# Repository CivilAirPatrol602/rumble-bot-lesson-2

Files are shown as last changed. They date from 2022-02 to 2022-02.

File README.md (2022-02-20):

# Rumble-Bot Lesson 2

Lesson 2 focuses on soldering the Rumble-Bot microcontroller board and designing
the Rumble-Bot input/output board by placing components and copper traces.

## Directory Contents

* [01-power](01-power/README.md): The completed Ardustack power board; cadets
  assemble and solder a power board as part of Lesson 1
* [02-processor](02-processor/README.md): The completed Ardustack
  microcontroller board; cadets assemble and solder a microcontroller board as
  part of Lesson 2
* [03-input-output](03-input-output/README.md): The Ardustack input/output
  board; cadets place components and route the board traces as part of Lesson 2
* [LICENSE](LICENSE): License for the non-hardware portions of the repository
* [README.md](README.md): This document

## License

Written by Bradley Denby  
Other contributors: None

See the [LICENSE](LICENSE) file for license details.

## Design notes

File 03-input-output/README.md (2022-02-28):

# Ardustack Input/Output Board

The I/O PCB for Ardustack, a through-hole Arduino stack

## Directory Contents

* **3d-models**: Contains component `.stp` files for import
* **components**: Contains component `.lib` files for import
* **datasheets**: Contains component datasheets
* **documentation**: Contains `.pdf` documentation files
* **footprints**: Contains component `.kicad_mod` files for import
* **gerbers**: Contains the most recent set of Gerber files
* **kicad**: Contains the KiCad project files
* **versions**: Contains `.zip` files of Gerber files submitted for manufacture
* [BOM.csv](BOM.csv): Bill of materials
* [LICENSE](LICENSE): License for the Ardustack power management PCB hardware
* [NOTES.md](NOTES.md): Useful notes if setting up a KiCad project from scratch
* [README.md](README.md): This document

## License

Written by Bradley Denby  
Other contributors: None

The Ardustack power management PCB is licensed as described in the
[LICENSE](LICENSE) file contained in this directory. All other materials, such
as documentation, are licensed as described in the top-level
[LICENSE](../LICENSE) file or under other applicable licenses.

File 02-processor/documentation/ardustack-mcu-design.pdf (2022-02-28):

## Ardustack MCU Board Design

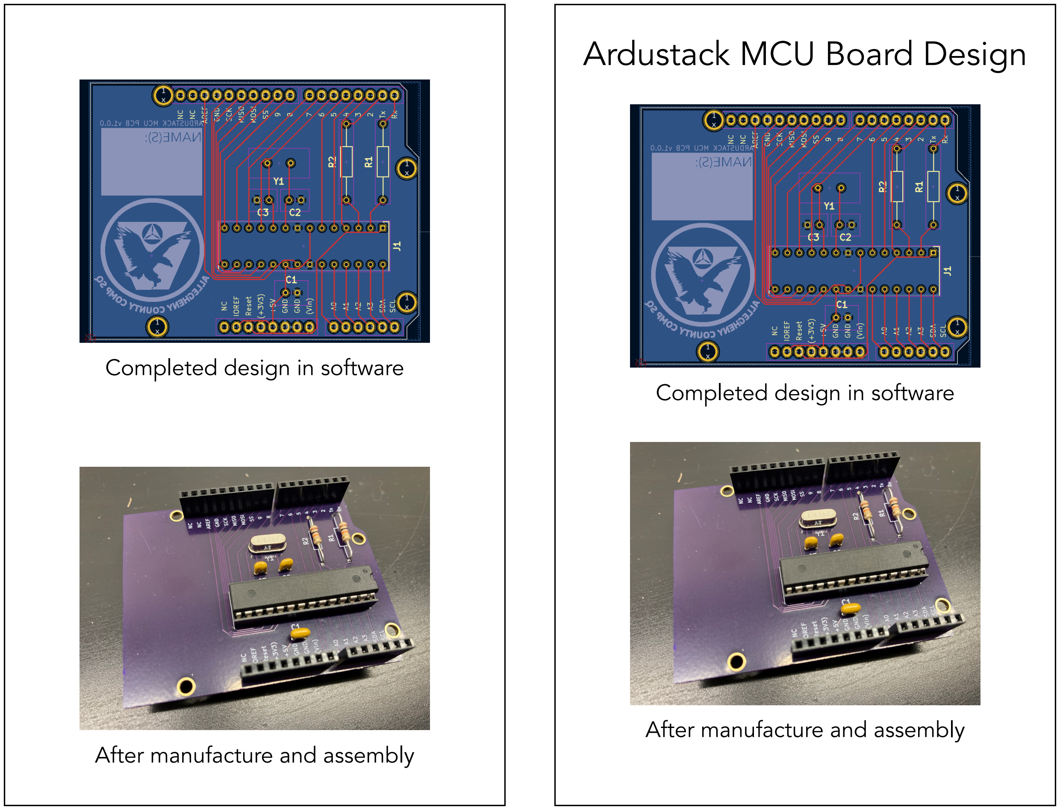
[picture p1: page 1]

Completed design in software

After manufacture and assembly

Completed design in software

After manufacture and assembly

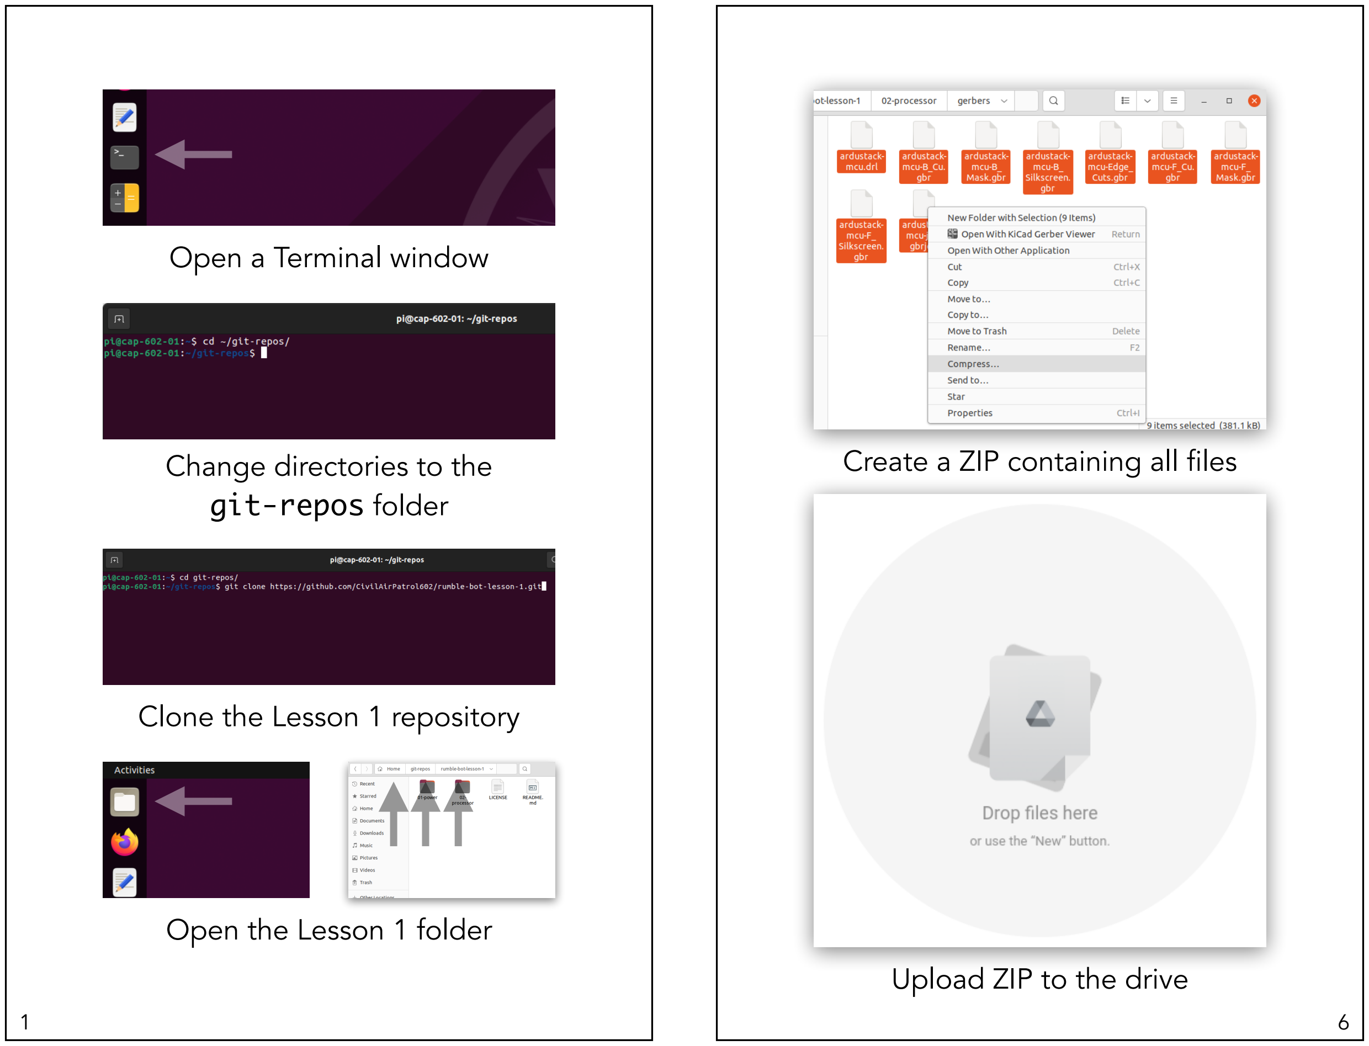
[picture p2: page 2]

Open a Terminal window

Change directories to the
git-repos folder

Clone the Lesson 1 repository

Open the Lesson 1 folder

Create a ZIP containing all files

Upload ZIP to the drive

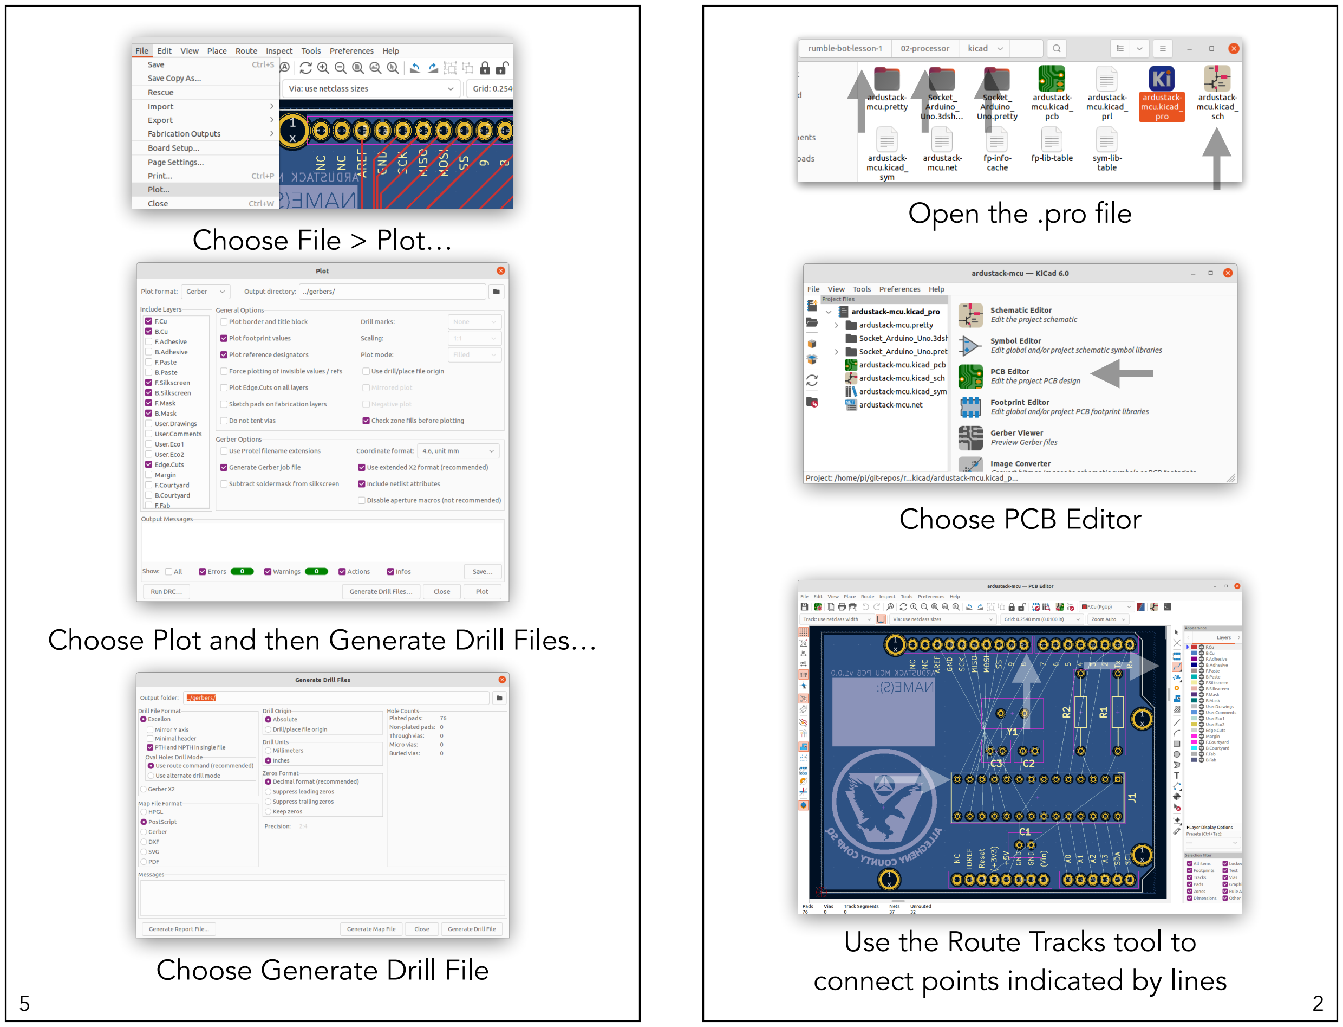
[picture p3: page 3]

Choose File > Plot…

Choose Plot and then Generate Drill Files…

Choose Generate Drill File

Open the .pro file

Choose PCB Editor

Use the Route Tracks tool to connect points indicated by lines

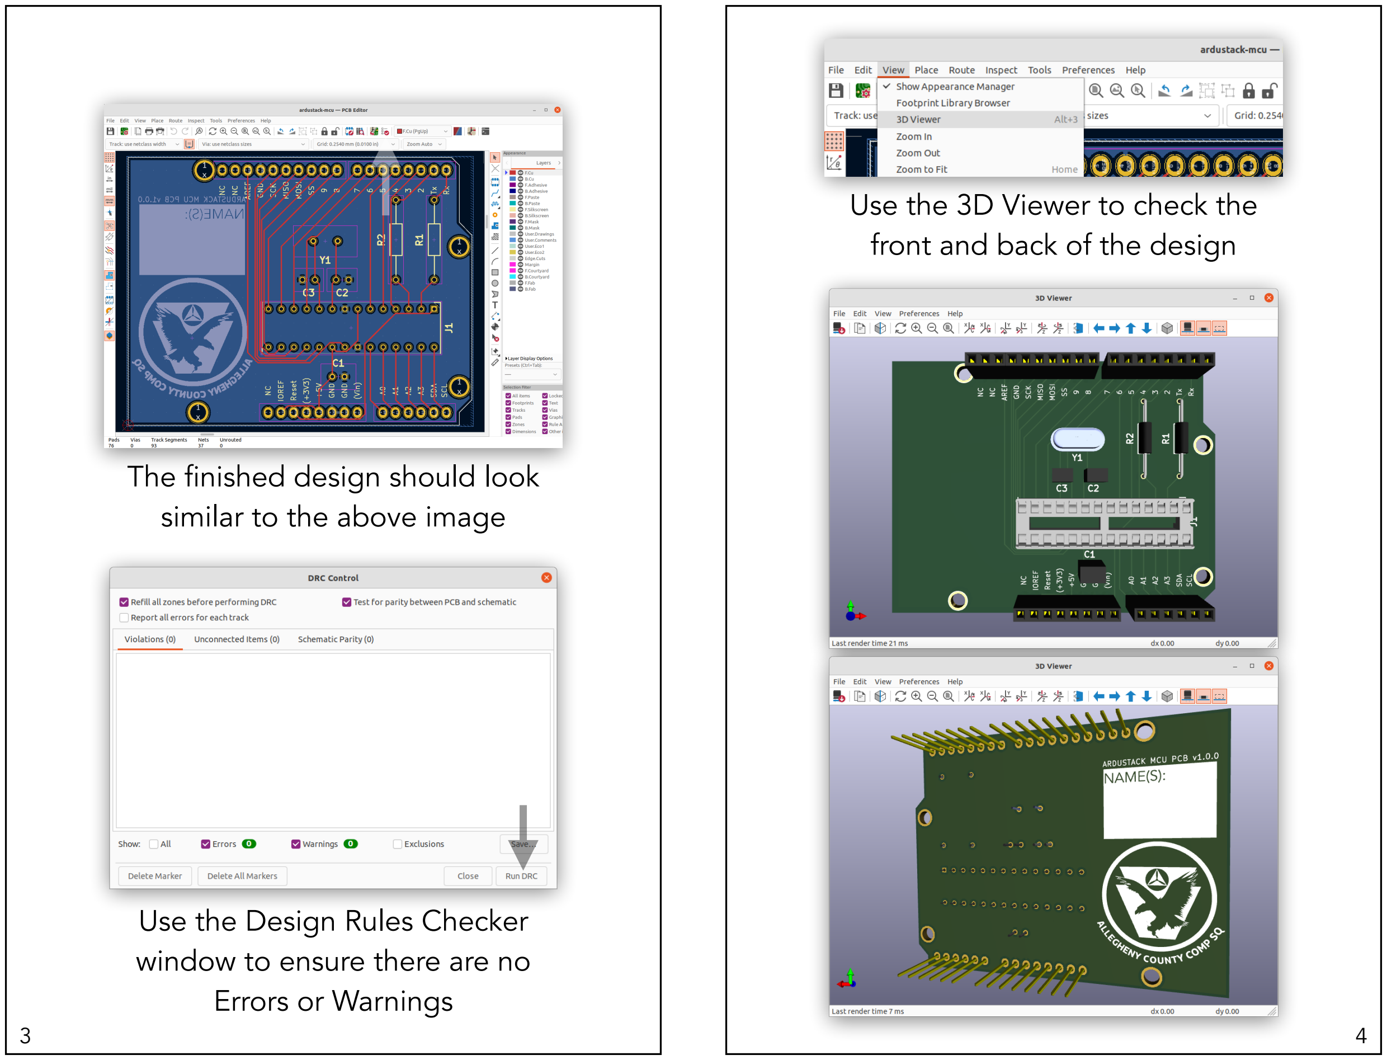
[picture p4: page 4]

The finished design should look similar to the above image

Use the Design Rules Checker window to ensure there are no Errors or Warnings

Use the 3D Viewer to check the front and back of the design

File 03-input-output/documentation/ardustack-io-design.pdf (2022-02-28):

## Ardustack I/O Board Design

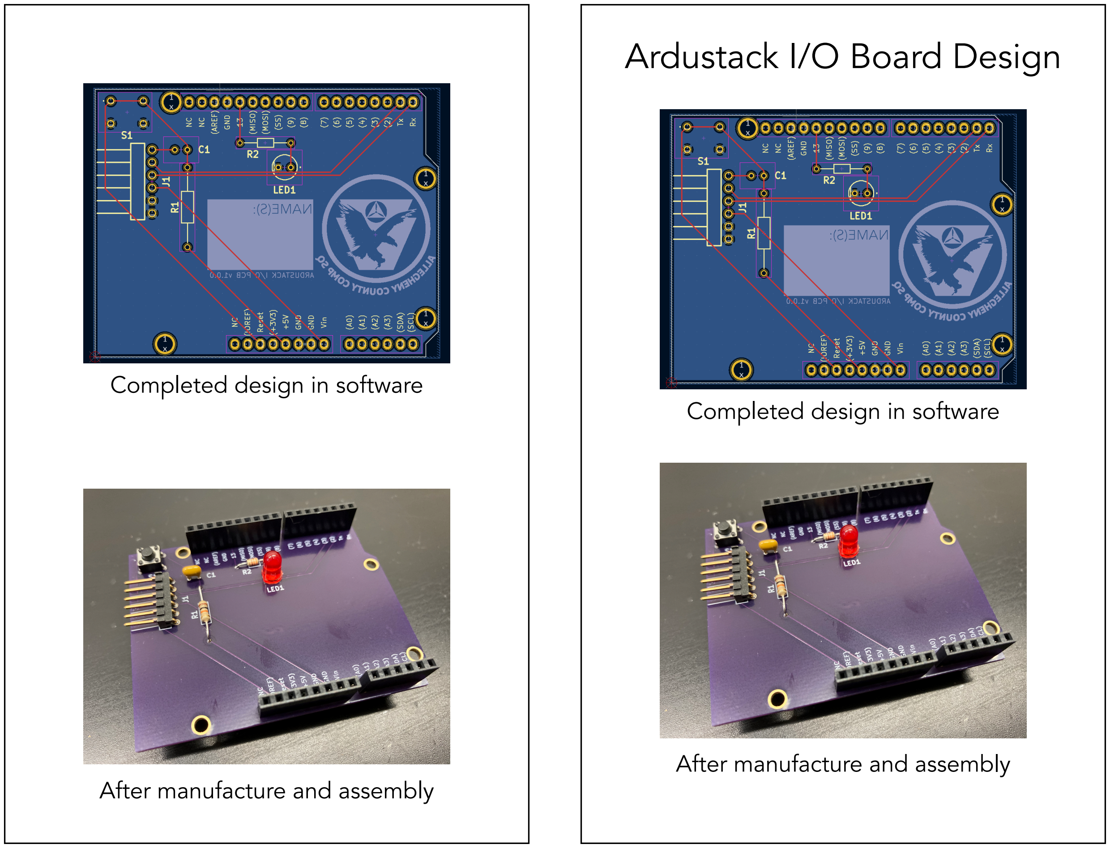
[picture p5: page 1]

Completed design in software

After manufacture and assembly

Completed design in software

After manufacture and assembly

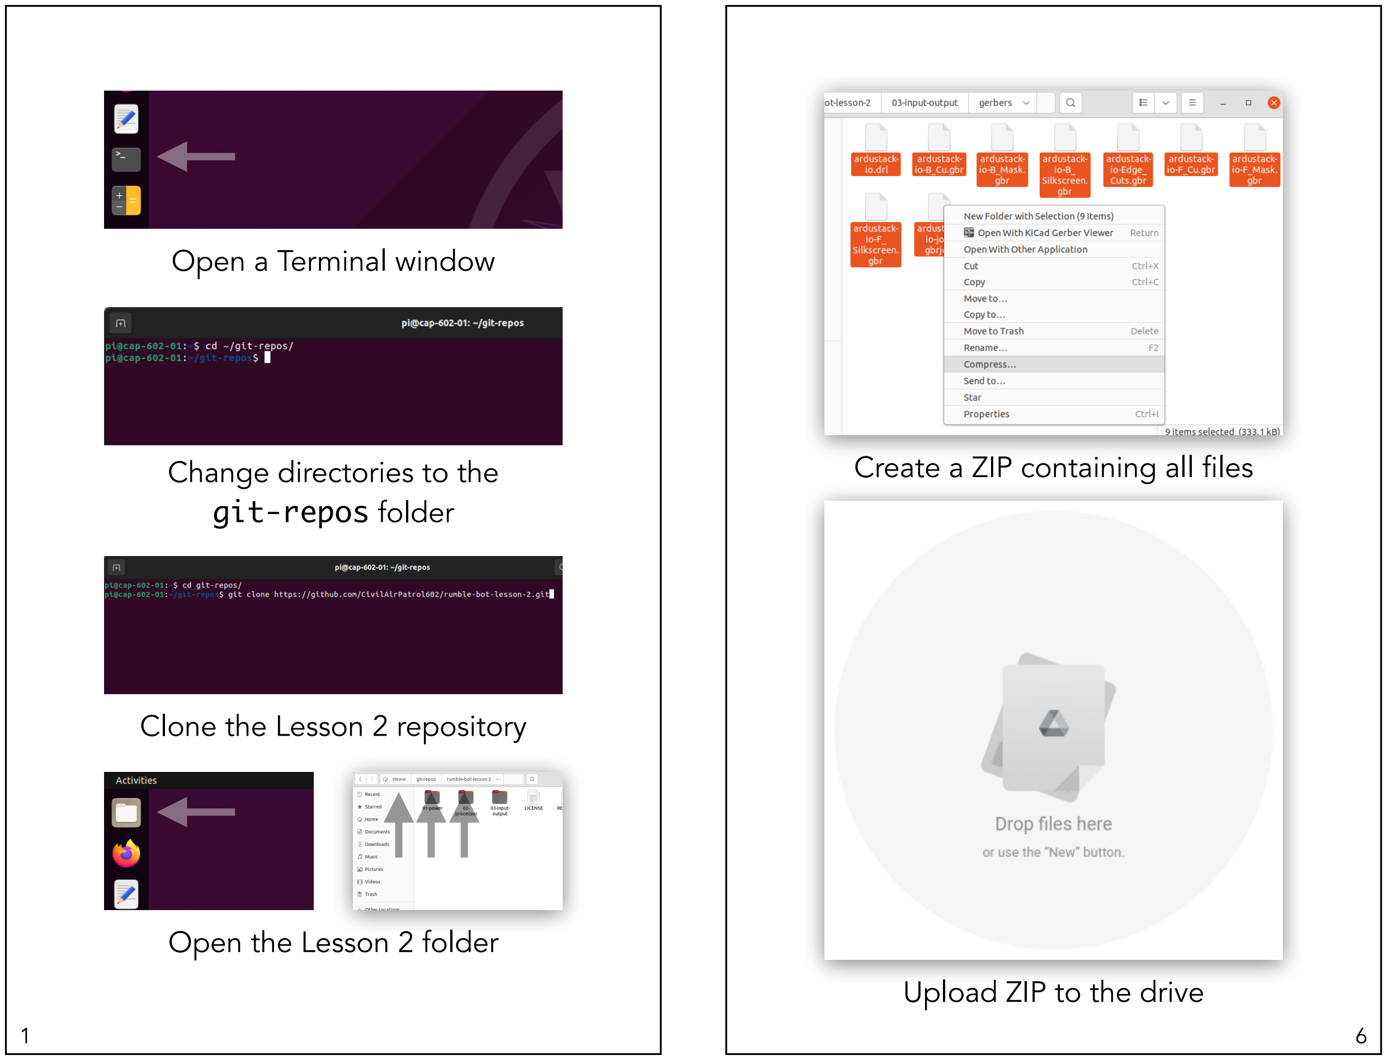
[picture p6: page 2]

Open a Terminal window

Change directories to the
git-repos folder

Clone the Lesson 2 repository

Open the Lesson 2 folder

Create a ZIP containing all files

Upload ZIP to the drive

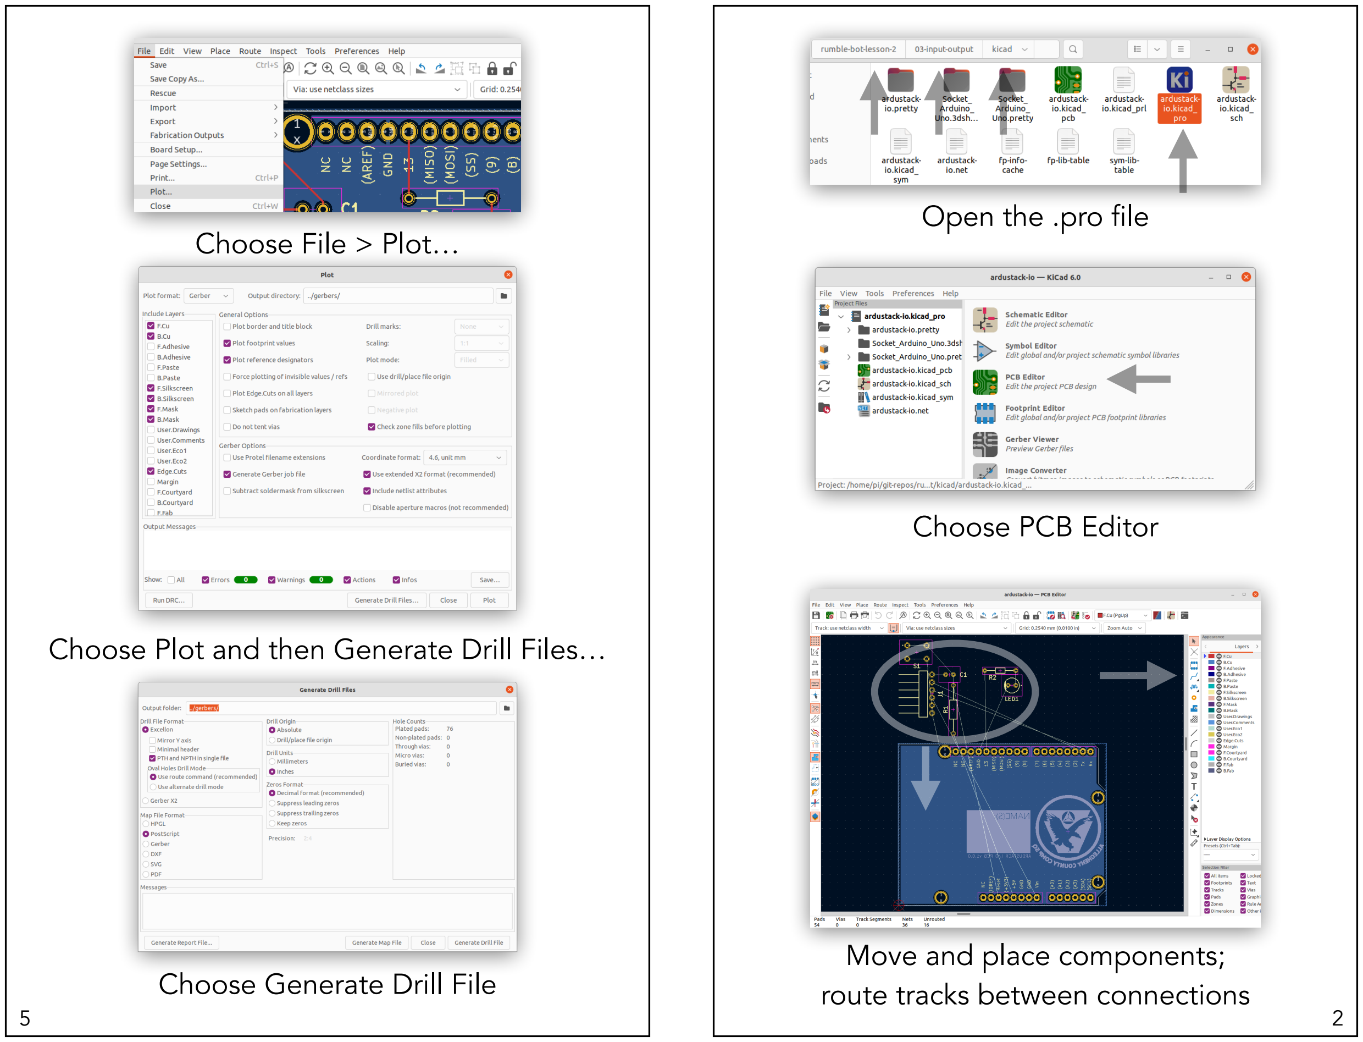
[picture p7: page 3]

Choose File > Plot…

Choose Plot and then Generate Drill Files…

Choose Generate Drill File

Open the .pro file

Choose PCB Editor

Move and place components; route tracks between connections

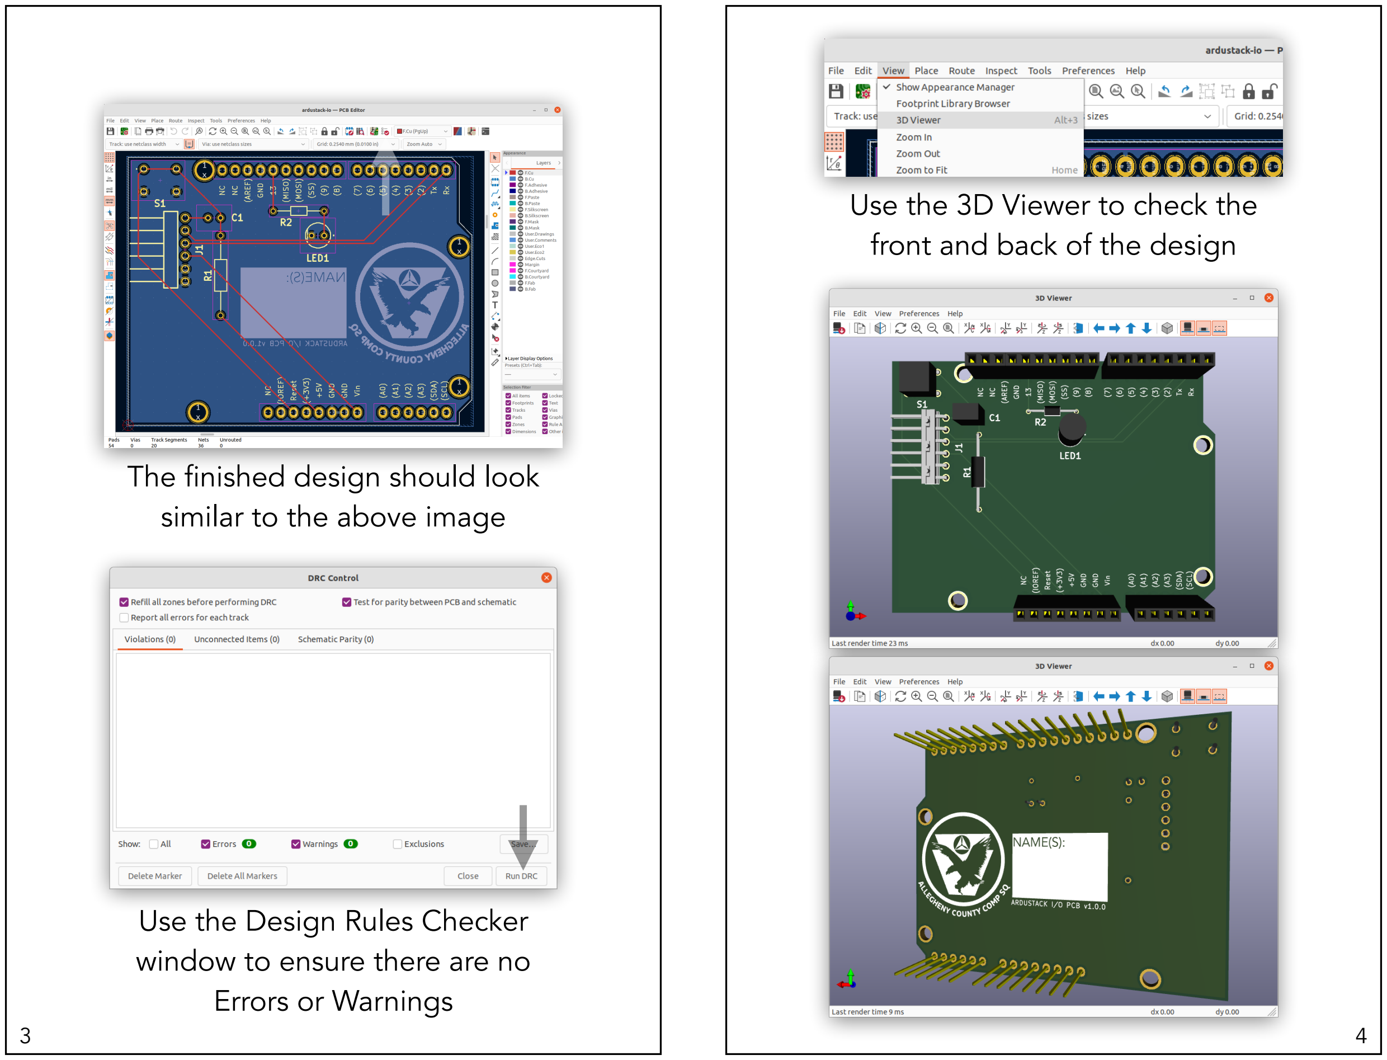
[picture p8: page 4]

The finished design should look similar to the above image

Use the Design Rules Checker window to ensure there are no Errors or Warnings

Use the 3D Viewer to check the front and back of the design

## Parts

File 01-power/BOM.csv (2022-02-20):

label | count | id | mouser | url | description
IC1 | 1 | MC7805CTG | 863-MC7805CTG | https://componentsearchengine.com/part-view/MC7805CTG/ON%20Semiconductor | Linear voltage regulator; Through hole TO-220-3; 1 Output; Positive; 5V; 1A; Fixed; 7-35V in; 25mV load reg.; 20mV line reg.; 0 - +125 C
IC2 | 1 | LP2950-33LPRE3 | 595-LP2950-33LPRE3 | https://componentsearchengine.com/part-view/LP2950-33LPRE3/Texas%20Instruments | LDO voltage regulator; Through hole TO-92-3; 1 Output; Positive; 3.3V; 100mA; Fixed; 2-30V in; 110mV dropout; 75uA quiescent; -40 - +125 C
J1 | 1 | CON-SOCJ-2155 | 992-CON-SOCJ-2155 | https://componentsearchengine.com/part-view/CON-SOCJ-2155/Gravitech | DC power connector; 2.1mm inside diameter; 5.5mm outside diameter; solder lug; right angle; DC power jack
C1; C2; C3 | 3 | K105Z20Y5VF5TL2 | 594-K105Z20Y5VF5TL2 | https://componentsearchengine.com/part-view/K105Z20Y5VF5TL2/Vishay | 1 uF; radial termination; 50V rating; -20% +80% tolerance; -30 - +85 C

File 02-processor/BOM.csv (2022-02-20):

label | count | id | mouser | url | description
IC1 | 1 | ATMEGA328P-PU | 556-ATMEGA328P-PU | https://componentsearchengine.com/part-view/ATMEGA328P-PU/Microchip | 8-bit MCU; Through hole; PDIP-28; 32 kB program memory; 2 kB data RAM; 20 MHz maximum
Y1 | 1 | ABL-16.000MHZ-B2 | 815-ABL-16-B2 | https://componentsearchengine.com/part-view/ABL-16.000MHZ-B2/ABRACON | Crystal; Radial; HC-49/US; 18pF load capacitance; 16MHz frequency; 20PPM tolerance; 50PPM freq. Stab.; 40 Ohm ESR
C1 | 1 | K105Z20Y5VF5TL2 | 594-K105Z20Y5VF5TL2 | https://componentsearchengine.com/part-view/K105Z20Y5VF5TL2/Vishay | 1 uF; radial termination; 50V rating; -20% +80% tolerance; -30 - +85 C
C2; C3 | 2 | K220J15C0GF5TL2 | 594-K220J15C0GF5TL2 | https://componentsearchengine.com/part-view/K220J15C0GF5TL2/Vishay | 22 pF; radial termination; 50V rating; 5% tolerance; -55 - +125 C
R1; R2 | 2 | CFR-25JR-52-10K | 603-CFR-25JR-5210K | https://componentsearchengine.com/part-view/CFR-25JR-52-10K/YAGEO%20(PHYCOMP) | 10 kOhm; axial termination; 250V rating; 5% tolerance; 250mW power rating; -55 - +155 C
J1 | 1 | 1-2199298-9 | 571-1-2199298-9 | https://componentsearchengine.com/part-view/1-2199298-9/TE%20Connectivity | Through hole; socket pins; 28 position; 2 row; 2.54 mm pitch; 7.62 mm row spacing

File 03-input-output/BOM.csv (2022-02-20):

label | count | id | mouser | url | description
J1 | 1 | 825437-6 | 571-825437-6 | https://componentsearchengine.com/part-view/825437-6/TE%20Connectivity | Jumper for FTDI cable
LED1 | 1 | C503B-RCN-CW0Z0AA2 | 941-C503BRCNCW0Z0AA2 | https://componentsearchengine.com/part-view/C503B-RCN-CW0Z0AA2/Cree%2C%20Inc. | LED
C1 | 1 | K105Z20Y5VF5TL2 | 594-K105Z20Y5VF5TL2 | https://componentsearchengine.com/part-view/K105Z20Y5VF5TL2/Vishay | 1 uF; radial termination; 50V rating; -20% +80% tolerance; -30 - +85 C
R1 | 1 | CFR-25JR-52-10K | 603-CFR-25JR-5210K | https://componentsearchengine.com/part-view/CFR-25JR-52-10K/YAGEO%20(PHYCOMP) | 10 kOhm; axial termination; 250V rating; 5% tolerance; 250mW power rating; -55 - +155 C
R2 | 1 | CFS1/4C331J | 660-CFS1/4C331J | https://componentsearchengine.com/part-view/CFS1%2F4C331J/KOA%20Speer | 330 Ohm; axial termination; 250V rating; 5% tolerance; 250mW power rating; -55 - +155 C
S1 | 1 | PTS645SL502LFS | 611-PTS645SL502 | https://componentsearchengine.com/part-view/PTS645SL502LFS/C%20%26%20K%20COMPONENTS | Switch; Non-illuminated; Through-hole; Off - (On); 50mA current rating; 12V voltage rating; SPST

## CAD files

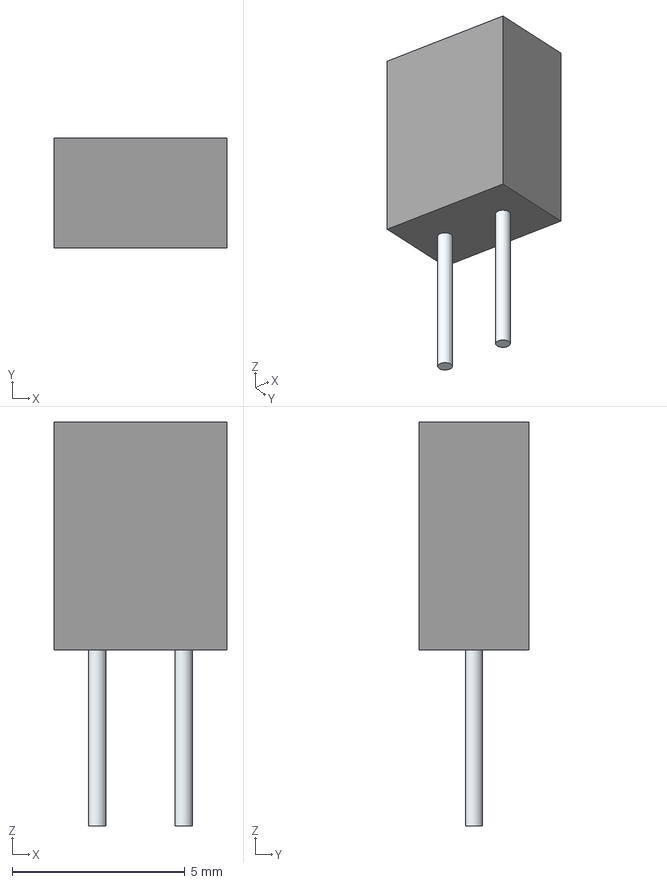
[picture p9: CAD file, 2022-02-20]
01-power/3d-models/K105Z20Y5VF5TL2.stp
5.00 x 3.20 x 11.7 mm
Leads

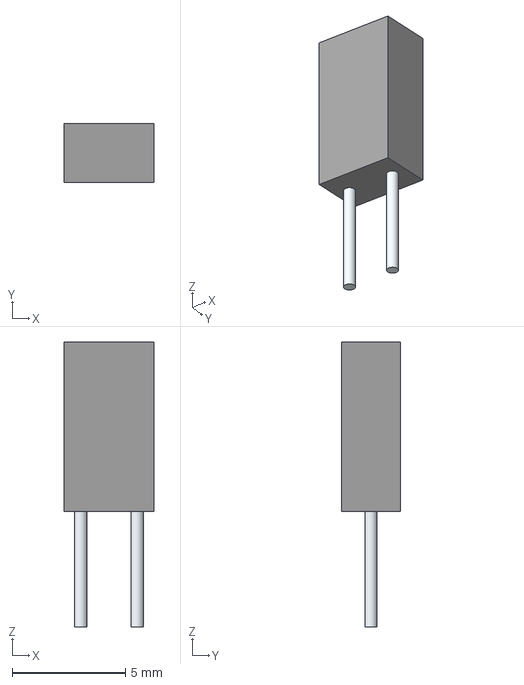
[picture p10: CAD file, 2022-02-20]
02-processor/3d-models/K220J15C0GF5TL2.stp
4.00 x 2.60 x 12.6 mm
Leads

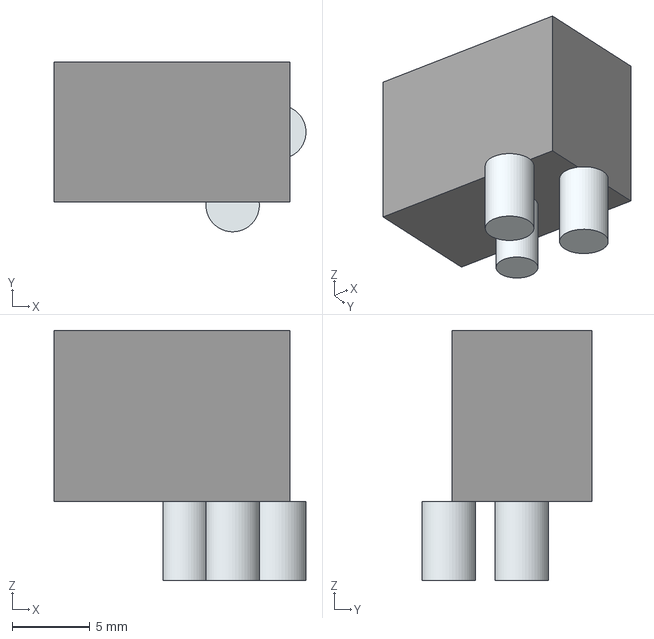
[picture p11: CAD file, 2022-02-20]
01-power/3d-models/CONSOCJ2155.stp
16.2 x 10.9 x 16.1 mm
Leads x 3

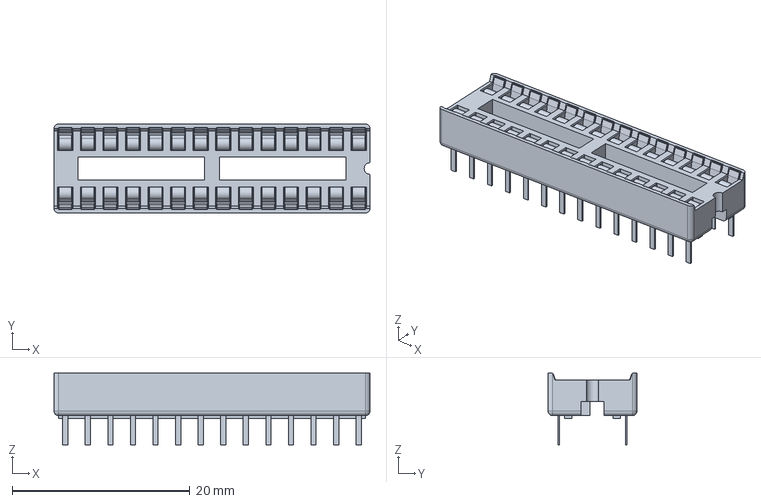
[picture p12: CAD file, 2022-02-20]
02-processor/3d-models/DIPS1524W51P254L3556H457Q28N.stp
35.6 x 10.0 x 8.10 mm

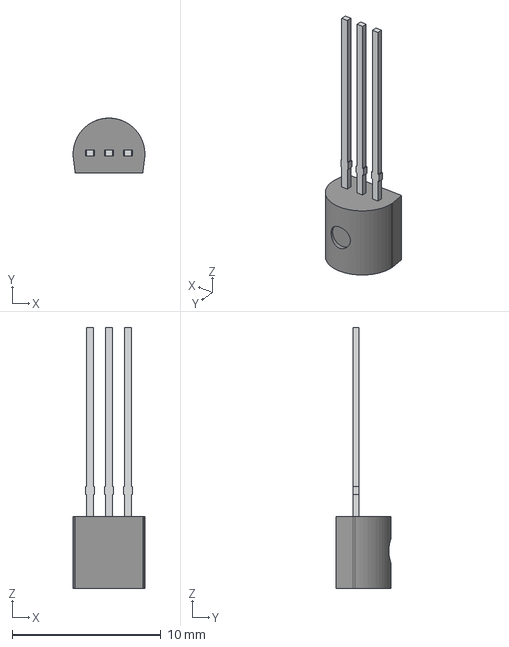
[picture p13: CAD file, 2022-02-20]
01-power/3d-models/TL431CLP.stp
4.83 x 3.68 x 17.5 mm
BODY-TO92
LEAD-TO92 x 3

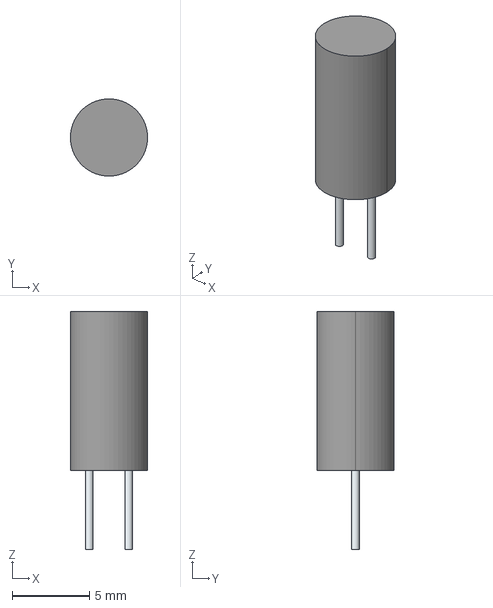
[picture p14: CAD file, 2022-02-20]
03-input-output/3d-models/C503BRCNCW0Z0AA2.stp
5.00 x 5.00 x 15.4 mm
Leads

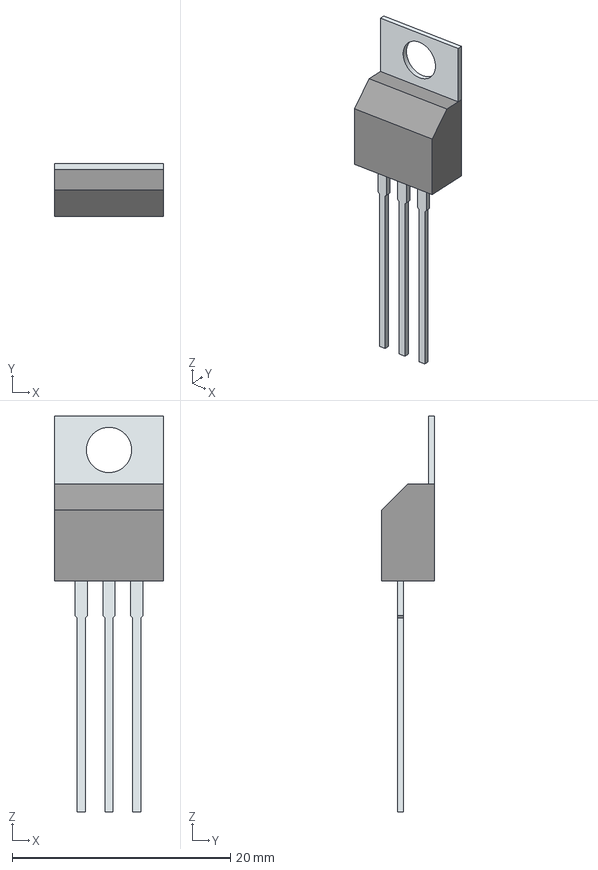
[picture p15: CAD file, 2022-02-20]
01-power/3d-models/TO254P482X997X2018-3P.stp
9.97 x 4.82 x 36.3 mm
Tab
PinsArray

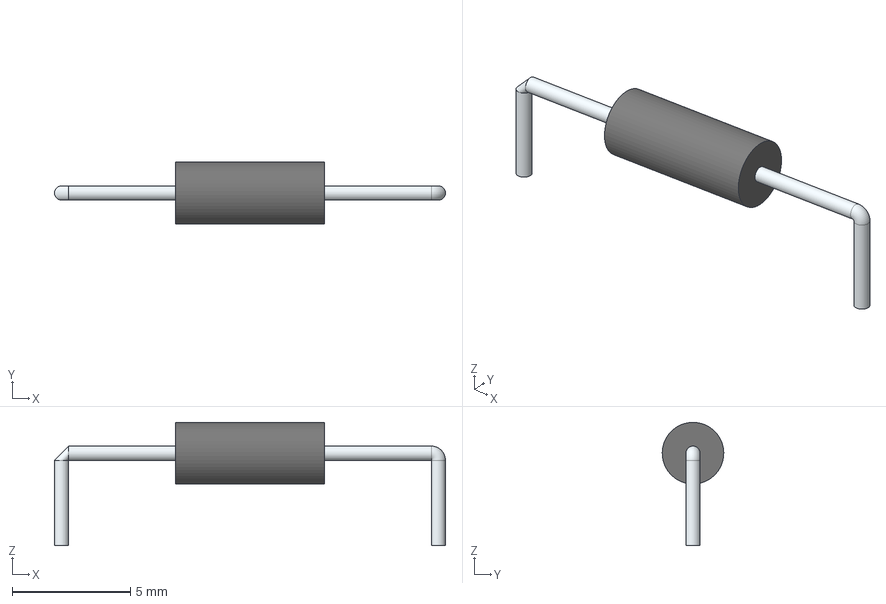
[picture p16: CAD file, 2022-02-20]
02-processor/3d-models/RESAD1590W60L630D240.stp
16.5 x 2.60 x 5.20 mm
SimpleBody

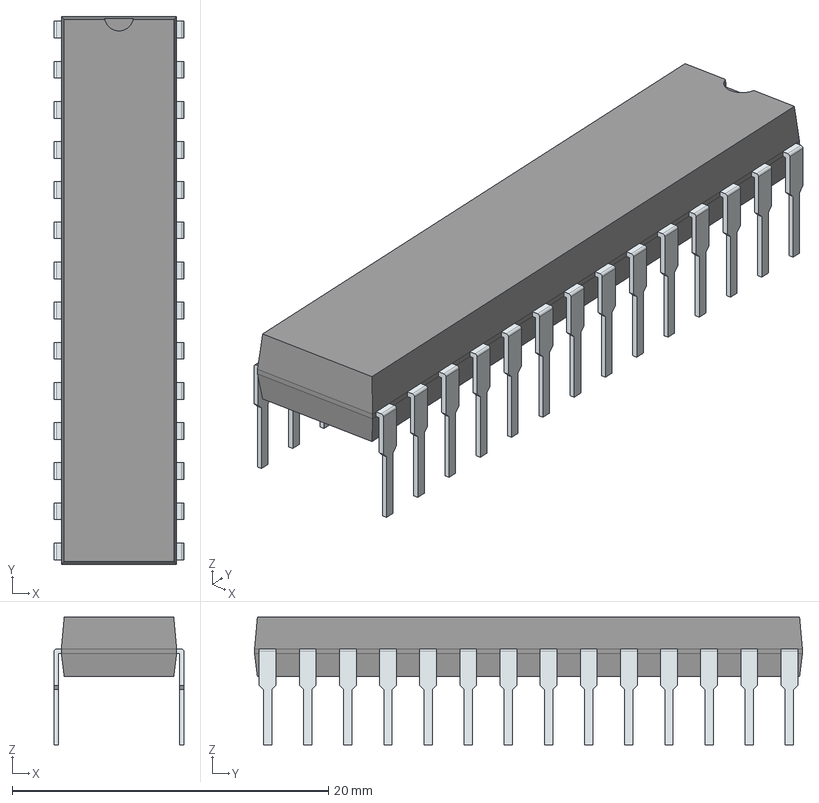
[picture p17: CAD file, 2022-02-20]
02-processor/3d-models/DIP794W53P254L3467H457Q28N.stp
8.20 x 34.7 x 8.07 mm
PinsArrayLR

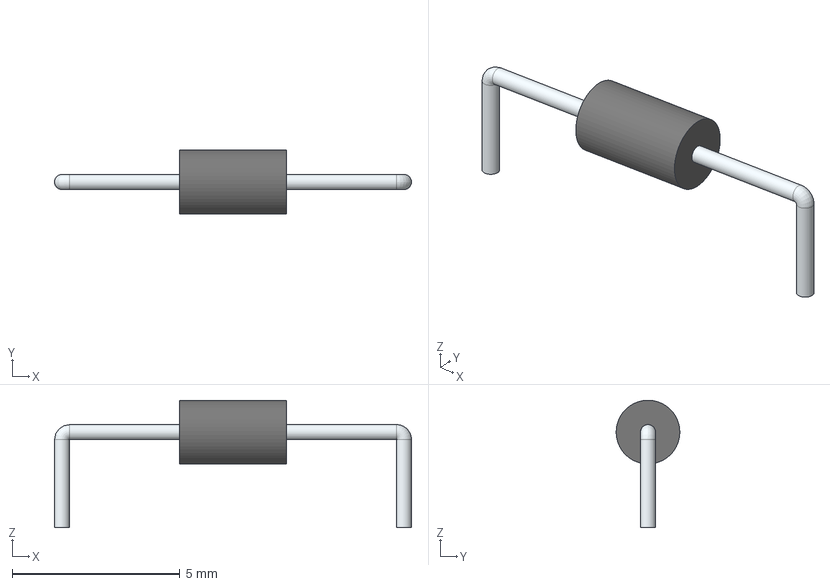
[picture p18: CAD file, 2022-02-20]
03-input-output/3d-models/RESAD1020W45L320D175.stp
10.6 x 1.90 x 3.80 mm
SimpleBody

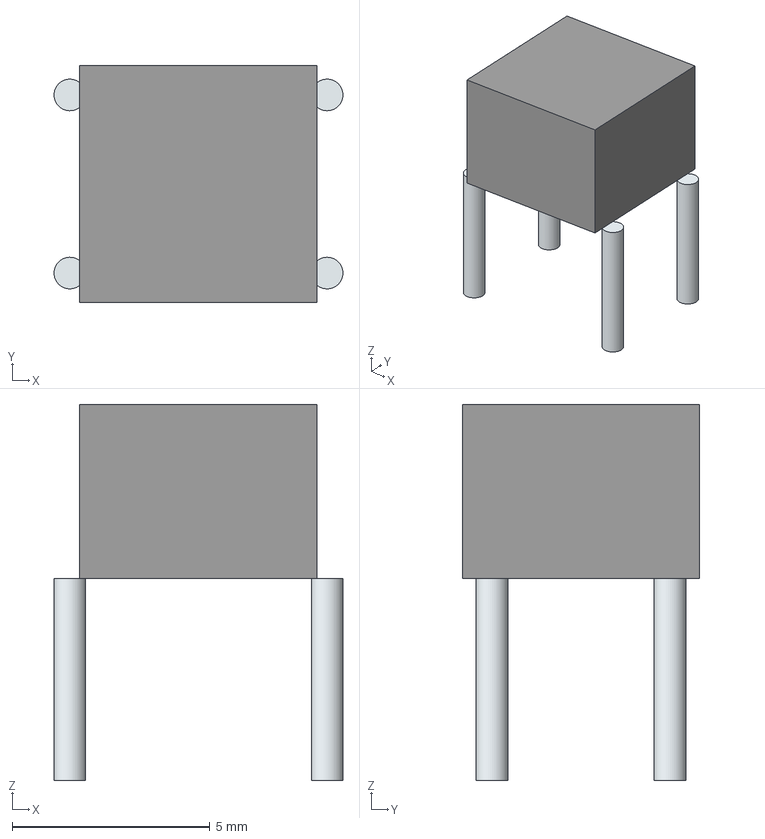
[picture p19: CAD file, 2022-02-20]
03-input-output/3d-models/PTS645SL502LFS.stp
7.30 x 6.00 x 9.50 mm
Leads x 4

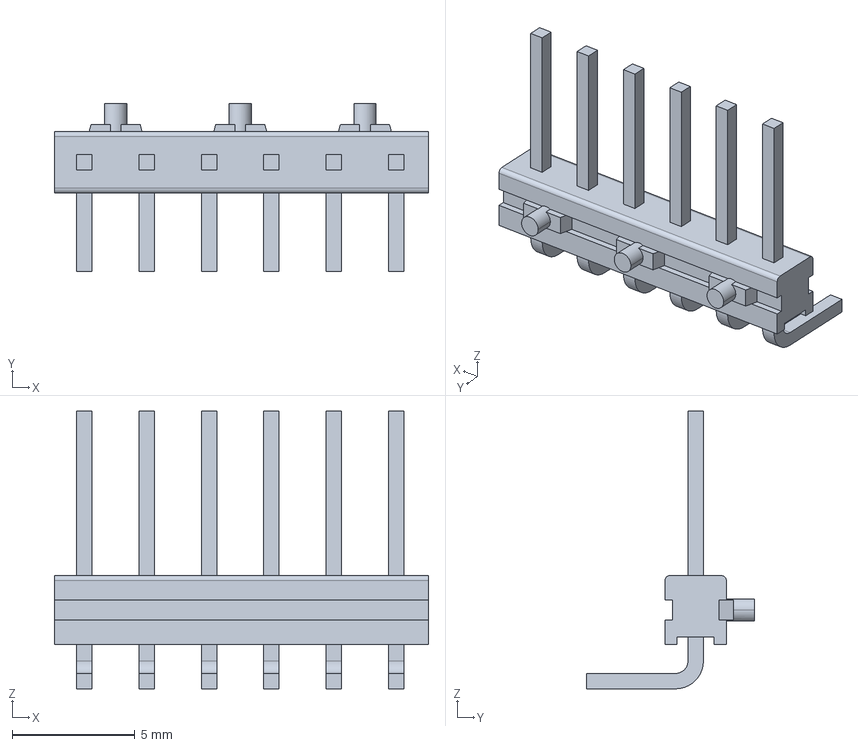
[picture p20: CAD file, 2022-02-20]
03-input-output/3d-models/825437-6.stp
15.2 x 6.85 x 11.3 mm

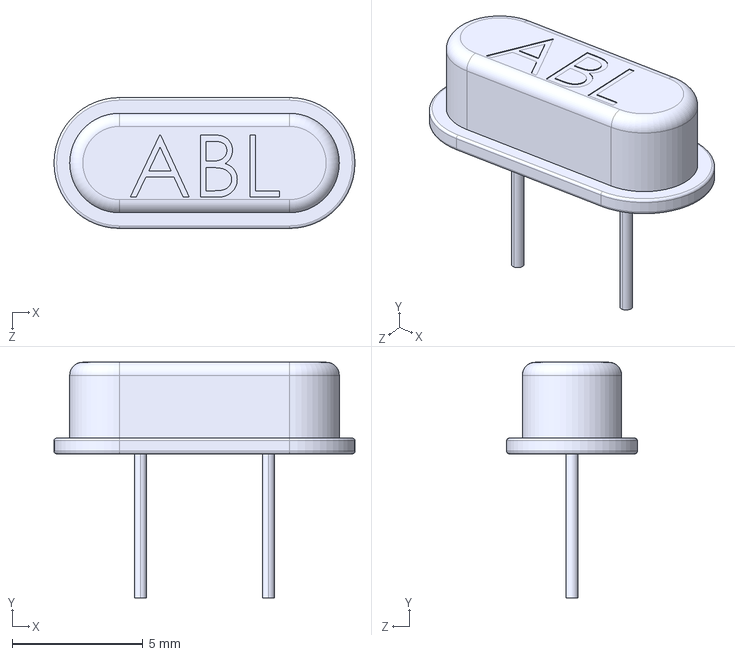
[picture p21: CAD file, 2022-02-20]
02-processor/3d-models/ABL16000MHZB2.stp
11.5 x 9.00 x 5.00 mm

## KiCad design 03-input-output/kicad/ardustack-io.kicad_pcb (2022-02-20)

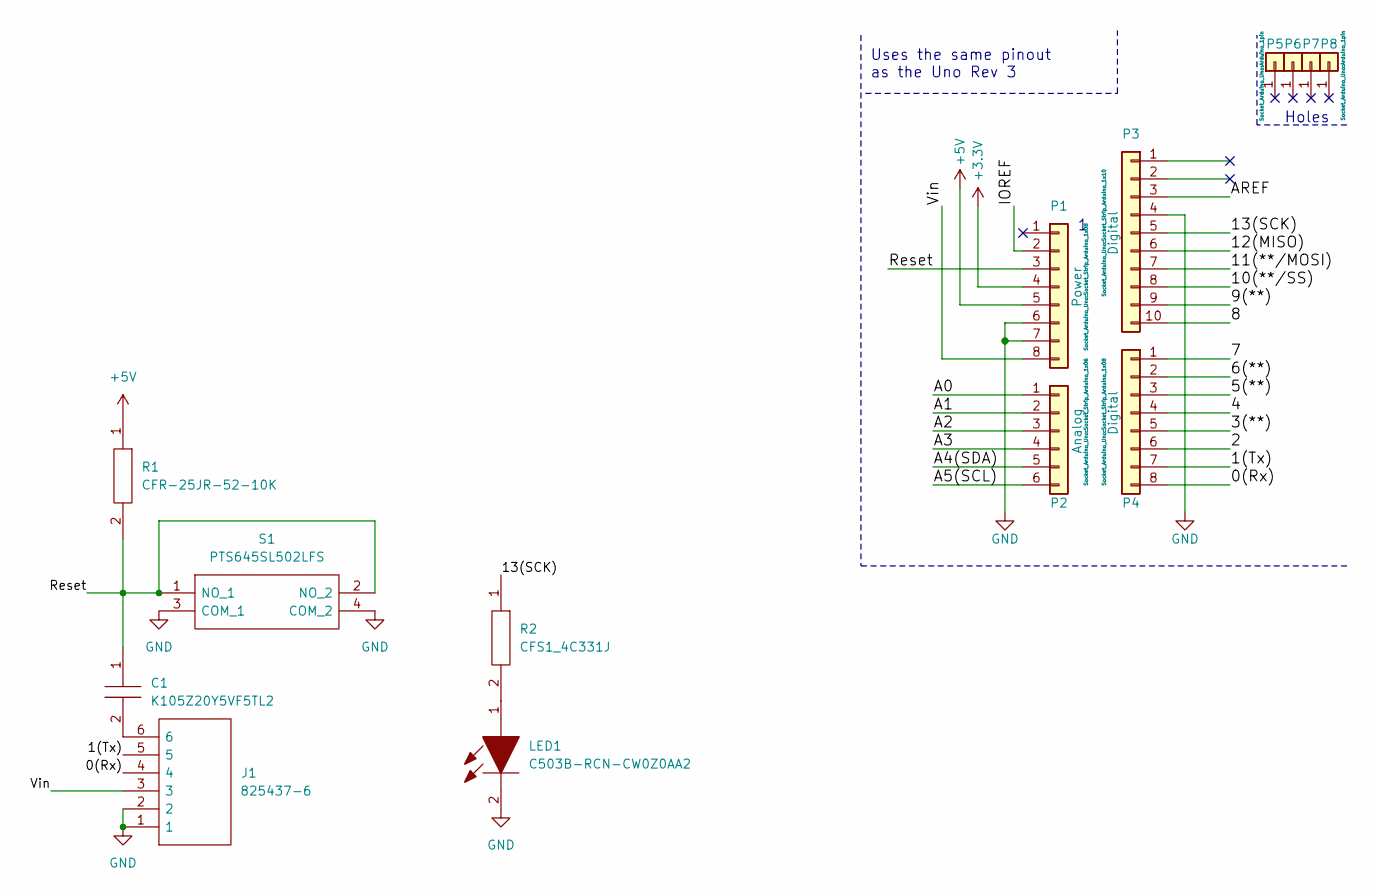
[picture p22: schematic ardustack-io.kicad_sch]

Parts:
C1: K105Z20Y5VF5TL2; Manufacturer_Part_Number K105Z20Y5VF5TL2; Mouser Part Number 594-K105Z20Y5VF5TL2
J1: 825437-6; Manufacturer_Part_Number 825437-6; Mouser Part Number 571-825437-6
LED1: C503B-RCN-CW0Z0AA2; C503BRCNCW0Z0AA2; Manufacturer_Part_Number C503B-RCN-CW0Z0AA2; Mouser Part Number 941-C503BRCNCW0Z0AA2
P1: Power; Socket_Strip_Arduino_1x08
P2: Analog; Socket_Strip_Arduino_1x06
P3: Digital; Socket_Strip_Arduino_1x10
P4: Digital; Socket_Strip_Arduino_1x08
P5, P6, P7, P8: CONN_01X01; Arduino_1pin
R1: CFR-25JR-52-10K; RESAD1590W60L630D240; Manufacturer_Part_Number CFR-25JR-52-10K; Mouser Part Number 603-CFR-25JR-5210K
R2: CFS1_4C331J; RESAD1020W45L320D175; Manufacturer_Part_Number CFS1/4C331J; Mouser Part Number 660-CFS1/4C331J
S1: PTS645SL502LFS; Manufacturer_Part_Number PTS645SL502LFS; Mouser Part Number 611-PTS645SL502

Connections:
+3V3: P1.4
+5V: P1.5, R1.1
/0(Rx): J1.4, P4.8
/1(Tx): J1.5, P4.7
/2: P4.6
/3(**): P4.5
/4: P4.4
/5(**): P4.3
/6(**): P4.2
/7: P4.1
/8: P3.10
/9(**): P3.9
/10(**/SS): P3.8
/11(**/MOSI): P3.7
/12(MISO): P3.6
/13(SCK): P3.5, R2.1
/A0: P2.1
/A1: P2.2
/A2: P2.3
/A3: P2.4
/A4(SDA): P2.5
/A5(SCL): P2.6
/AREF: P3.3
/IOREF: P1.2
/Reset: C1.1, P1.3, R1.2, S1.1 (NO_1), S1.2 (NO_2)
/Vin: J1.3, P1.8
GND: J1.1, J1.2, LED1.2, P1.6, P1.7, P3.4, S1.3 (COM_1), S1.4 (COM_2)
unnamed: C1.2, J1.6
unnamed: LED1.1, R2.2

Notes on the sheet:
Holes
Uses the same pinout as the Uno Rev 3

Board: 2 copper layers, 14 parts (0 on the bottom side), 9 nets, no tracks yet.

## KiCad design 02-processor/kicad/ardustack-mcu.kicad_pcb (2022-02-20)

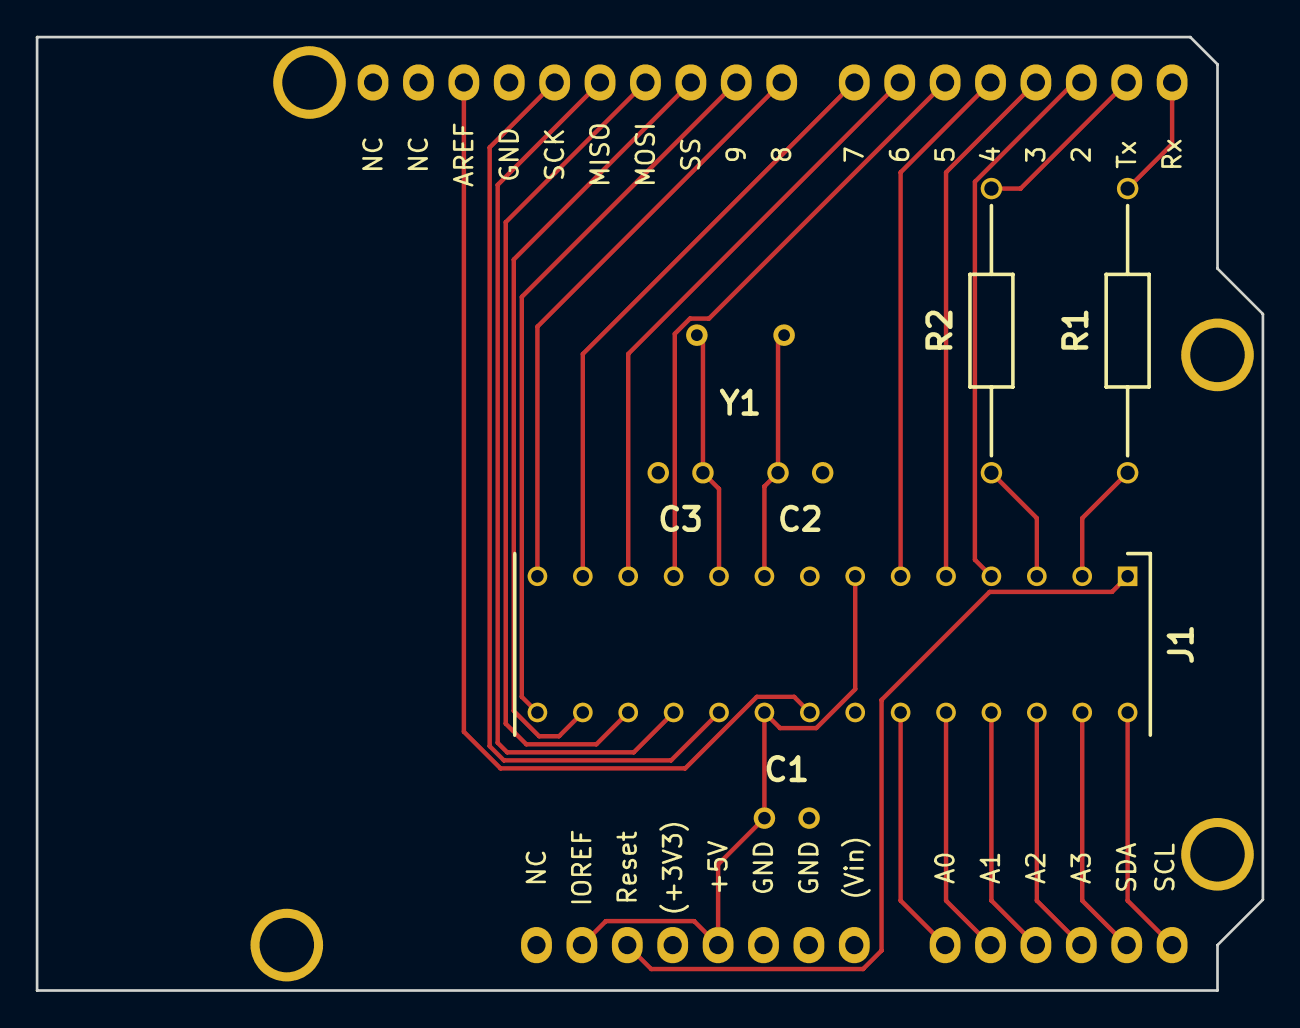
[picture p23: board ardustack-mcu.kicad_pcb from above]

Board: 2 copper layers, 68.6 x 53.3 mm, 15 parts (0 on the bottom side), 28 nets.

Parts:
C1: K105Z20Y5VF5TL2
C2, C3: K220J15C0GF5TL2
J1: 1-2199298-9; DIPS1524W51P254L3556H457Q28N
P1: Power; Socket_Strip_Arduino_1x08
P2: Analog; Socket_Strip_Arduino_1x06
P3: Digital; Socket_Strip_Arduino_1x10
P4: Digital; Socket_Strip_Arduino_1x08
P5, P6, P7, P8: CONN_01X01; Arduino_1pin
R1, R2: CFR-25JR-52-10K; RESAD1590W60L630D240
Y1: ABL-16.000MHZ-B2; ABL16000MHZB2

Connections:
+5V: C1.1, J1.7, J1.20, P1.2, P1.5
/0(Rx): P4.8, R1.2
/1(Tx): P4.7, R2.2
/2: J1.4, P4.6
/3(**): J1.5, P4.5
/4: J1.6, P4.4
/5(**): J1.11, P4.3
/6(**): J1.12, P4.2
/7: J1.13, P4.1
/8: J1.14, P3.10
/9(**): J1.15, P3.9
/10(**/SS): J1.16, P3.8
/11(**/MOSI): J1.17, P3.7
/12(MISO): J1.18, P3.6
/13(SCK): J1.19, P3.5
/A0: J1.23, P2.1
/A1: J1.24, P2.2
/A2: J1.25, P2.3
/A3: J1.26, P2.4
/A4(SDA): J1.27, P2.5
/A5(SCL): J1.28, P2.6
/AREF: J1.21, P3.3
/CLK1: C2.1, J1.9, Y1.1 (X1)
/CLK2: C3.1, J1.10, Y1.2 (X2)
/Reset: J1.1, P1.3
GND: C1.2, C2.2, C3.2, J1.8, J1.22, P1.6, P1.7, P3.4
unnamed: J1.2, R1.1
unnamed: J1.3, R2.1

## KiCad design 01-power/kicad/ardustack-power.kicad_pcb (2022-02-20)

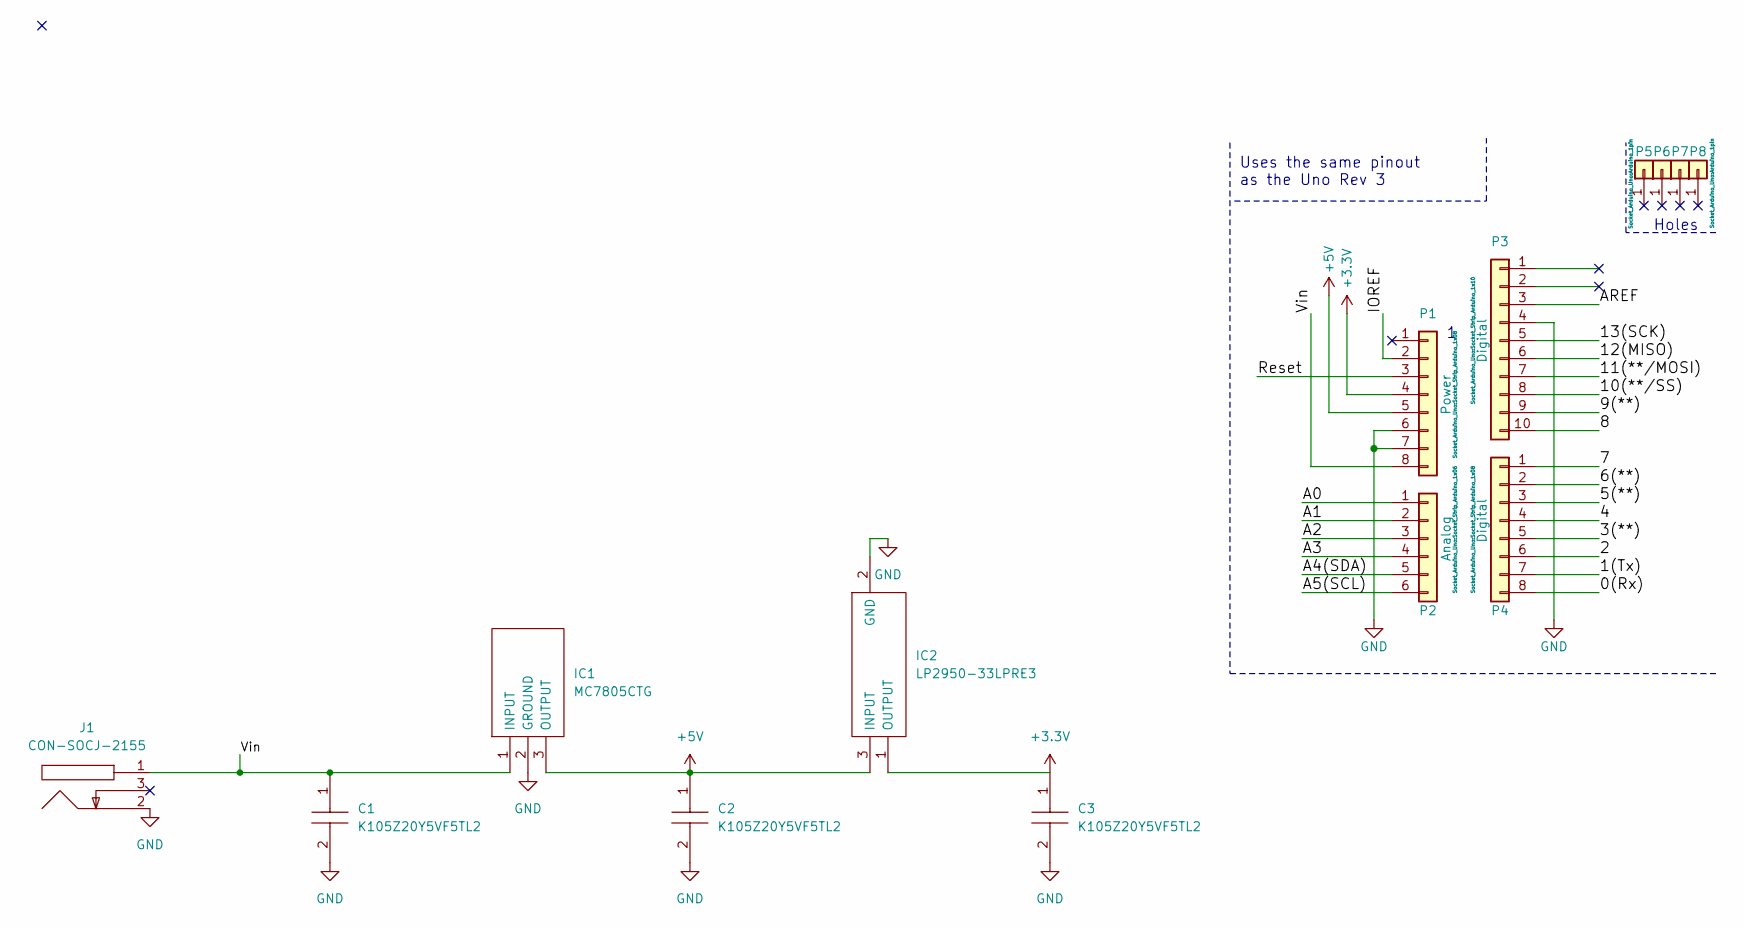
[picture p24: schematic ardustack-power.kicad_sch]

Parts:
C1, C2, C3: K105Z20Y5VF5TL2; Manufacturer_Part_Number K105Z20Y5VF5TL2; Mouser Part Number 594-K105Z20Y5VF5TL2
IC1: MC7805CTG; TO254P482X997X2018-3P; Manufacturer_Part_Number MC7805CTG; Mouser Part Number 863-MC7805CTG
IC2: LP2950-33LPRE3; TL431CLP; Manufacturer_Part_Number LP2950-33LPRE3; Mouser Part Number 595-LP2950-33LPRE3
J1: CON-SOCJ-2155; CONSOCJ2155; Manufacturer_Part_Number CON-SOCJ-2155; Mouser Part Number 992-CON-SOCJ-2155
P1: Power; Socket_Strip_Arduino_1x08
P2: Analog; Socket_Strip_Arduino_1x06
P3: Digital; Socket_Strip_Arduino_1x10
P4: Digital; Socket_Strip_Arduino_1x08
P5, P6, P7, P8: CONN_01X01; Arduino_1pin

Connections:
+3V3: C3.1, IC2.1 (OUTPUT), P1.4
+5V: C2.1, IC1.3 (OUTPUT), IC2.3 (INPUT), P1.5
/0(Rx): P4.8
/1(Tx): P4.7
/2: P4.6
/3(**): P4.5
/4: P4.4
/5(**): P4.3
/6(**): P4.2
/7: P4.1
/8: P3.10
/9(**): P3.9
/10(**/SS): P3.8
/11(**/MOSI): P3.7
/12(MISO): P3.6
/13(SCK): P3.5
/A0: P2.1
/A1: P2.2
/A2: P2.3
/A3: P2.4
/A4(SDA): P2.5
/A5(SCL): P2.6
/AREF: P3.3
/IOREF: P1.2
/Reset: P1.3
/Vin: C1.1, IC1.1 (INPUT), J1.1, P1.8
GND: C1.2, C2.2, C3.2, IC1.2 (GROUND), IC2.2 (GND), J1.2, P1.6, P1.7, P3.4

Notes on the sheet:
Holes
Uses the same pinout as the Uno Rev 3

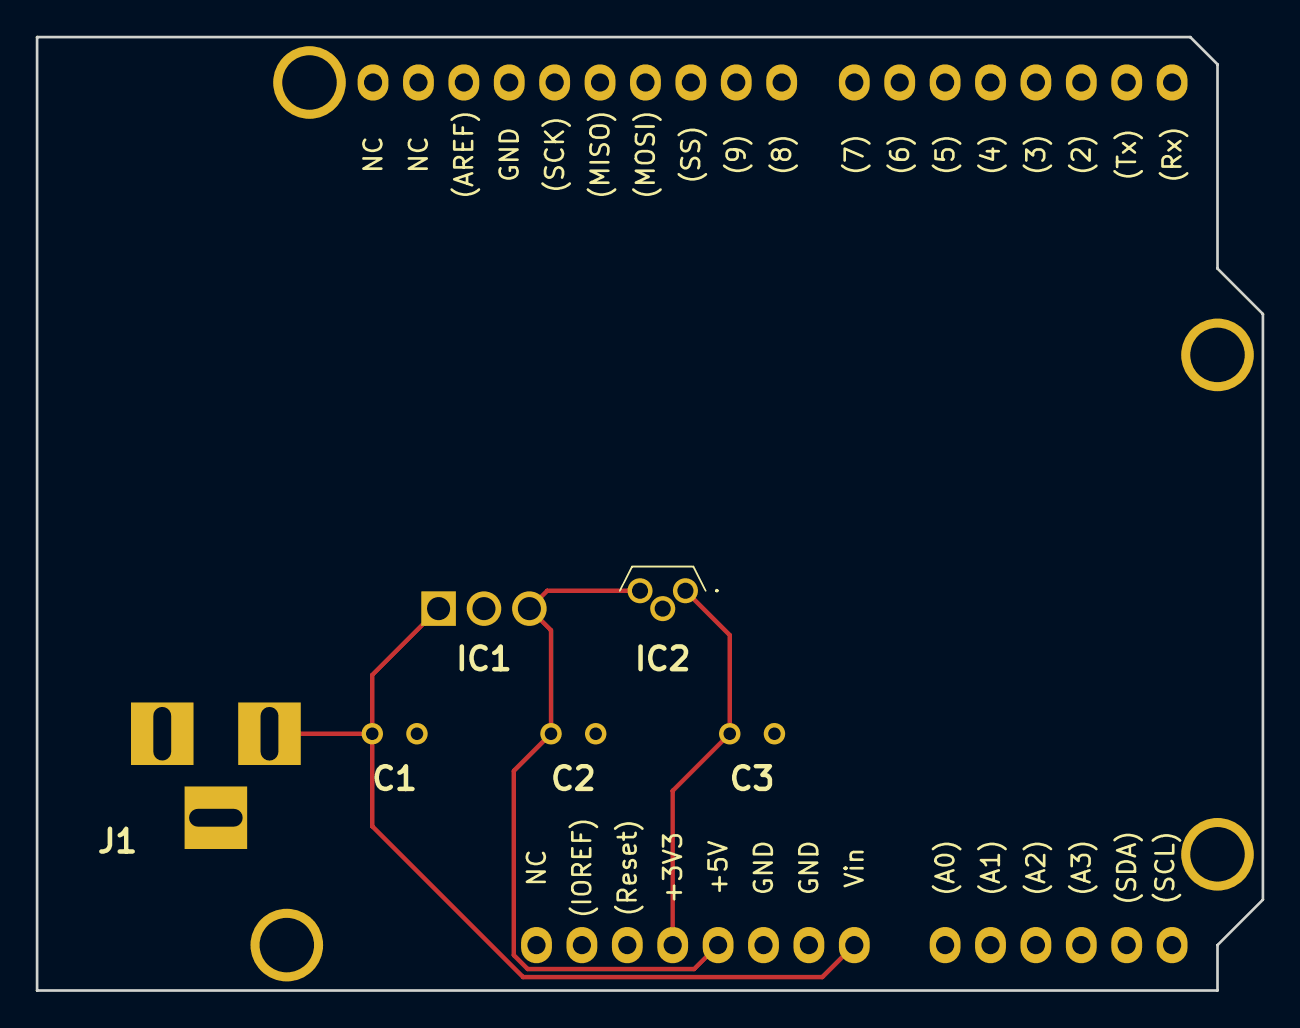
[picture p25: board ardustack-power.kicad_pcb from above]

Board: 2 copper layers, 68.6 x 53.3 mm, 14 parts (0 on the bottom side), 4 nets.
